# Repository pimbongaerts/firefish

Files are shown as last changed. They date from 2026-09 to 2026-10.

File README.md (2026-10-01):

# FireFish

### Real-time feedback &amp; synchronized sensor logging for underwater photogrammetry

An open-source microcontroller board that supports a wide range of sensors, and gives divers real-time
depth/altitude feedback, drives a dual-channel camera intervalometer, and logs time-stamped sensor data —
small enough to fit inside the smallest BlueRobotics 2″ underwater housing.








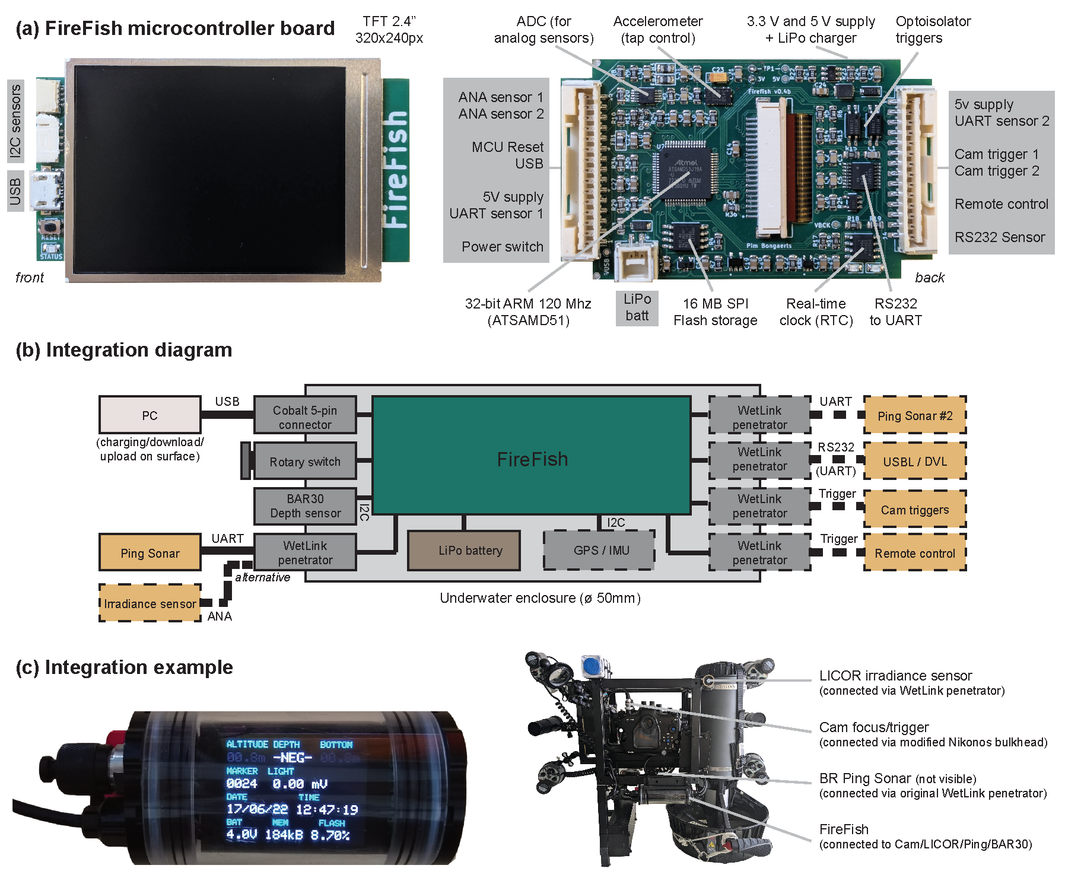
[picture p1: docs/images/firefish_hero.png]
The FireFish board (front and back), its system-integration diagram, and an example integration into a diver-propulsion-vehicle photogrammetry rig showing the live on-screen readout


---

## Overview

FireFish is a compact board that can provide scientific divers with (1) **real-time feedback** on depth, altitude,
and other positional data to guide image acquisition; (2) a programmable **dual-channel intervalometer** for one
or two cameras; and (3) **time-stamped logging** of sensor data that can be used for downstream photogrammetry model orientation. Its open design adapts well beyond photogrammetry — e.g. synchronized irradiance measurements or for underwater navigation – and provides an easy platform to make sensors designed for underwater vehicles accessible to divers.

<table>
<tr>
<td width="50%" valign="top">
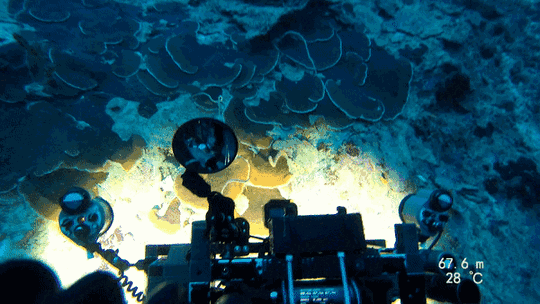
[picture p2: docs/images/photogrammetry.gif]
Diver conducting a coral-reef photogrammetry survey with FireFish

<br><sub><b>Photogrammetry.</b> The FireFish allows divers to maintain a fixed altitude from the live readout of a BlueRobotics Ping sonar, while simultaneously triggering a camera and logging depth/altitude for 3D-model orientation.</sub>
</td>
<td width="50%" valign="top">
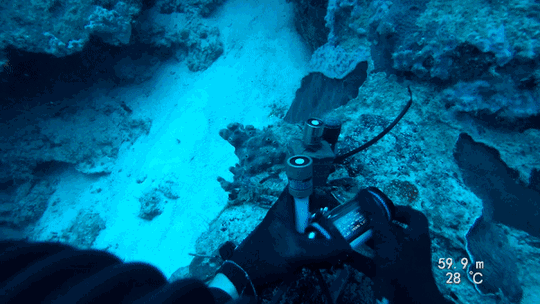
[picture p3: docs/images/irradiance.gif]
Diver logging underwater irradiance with FireFish

<br><sub><b>Irradiance measurements (alternative implementation).</b> The Reefscape Genomics Lab uses multiple FireFish units connected to LICOR irradiance sensors to conduct short-term irradiances measures across the reef, relative to time-synchronized measurements of the water column.</sub>
</td>
</tr>
</table>

## ✨ Features

- 🎯 **Live sensor readout** on a 2.4″ TFT — allowig divers to maintain a consistent altitude
- 📷 **Dual-channel intervalometer** — focus + shutter for one camera, or alternate-trigger two cameras
- ⏱️ **Synchronized logging** to onboard flash with a temperature-compensated RTC — easy model orientation
- 🔌 **Flexible I/O** — I²C (Qwiic / STEMMA QT), 2× UART, RS-232, and 2x analog inputs
- 🔋 **Onboard LiPo charging** — charge, download, and update firmware *through* the housing, no opening required
- 🤿 **Dive-ready** — fits standard 2″ (Ø50 mm) housings with 3D printed carrier; depth rating to 225 m
- 🛠️ **Fully open** — KiCad design, firmware, enclosure STLs, and an Arduino board-support package

## 🔧 Specifications

| | |
|---|---|
| **Microcontroller** | ATSAMD51J19A — 32-bit Arm Cortex-M4F, 120 MHz, hardware FPU |
| **Display** | 2.4″ TFT, 320 × 240 (ST7789) |
| **Storage** | 16 MB onboard SPI flash (MX25L12833F) |
| **Timekeeping** | DS3231MZ temperature-compensated RTC (battery-backed) |
| **Power** | MCP73831 single-cell LiPo charger; 3.3 V &amp; 5 V rails |
| **Sensing / I/O** | ADS1115 16-bit ADC; I²C, UART, RS-232 (MAX3232); tap gesture control |
| **Camera control** | Dual-channel optically-isolated intervalometer (TCMT1100) |
| **Board size** | 72 × 43 mm (two-layer PCB) |
| **Housing** | Standard 2″ (Ø50 mm) BlueRobotics enclosure; depth rating to 225 m |

## 📦 Repository contents

| Folder | Contents |
|---|---|
| [`hardware/`](hardware/) | KiCad 8 project — schematic, PCB layout, Gerbers, BOM, and pick-and-place files |
| [`firmware/`](firmware/) | Arduino board-support package (`firefish_m4_v4b`), an example sketch, and the bootloader |
| [`enclosure/`](enclosure/) | 3D-printable PETG carrier STLs (short / short-simple / long-simple) + clamp |
| [`docs/`](docs/) | Figures and documentation |

## Schematic

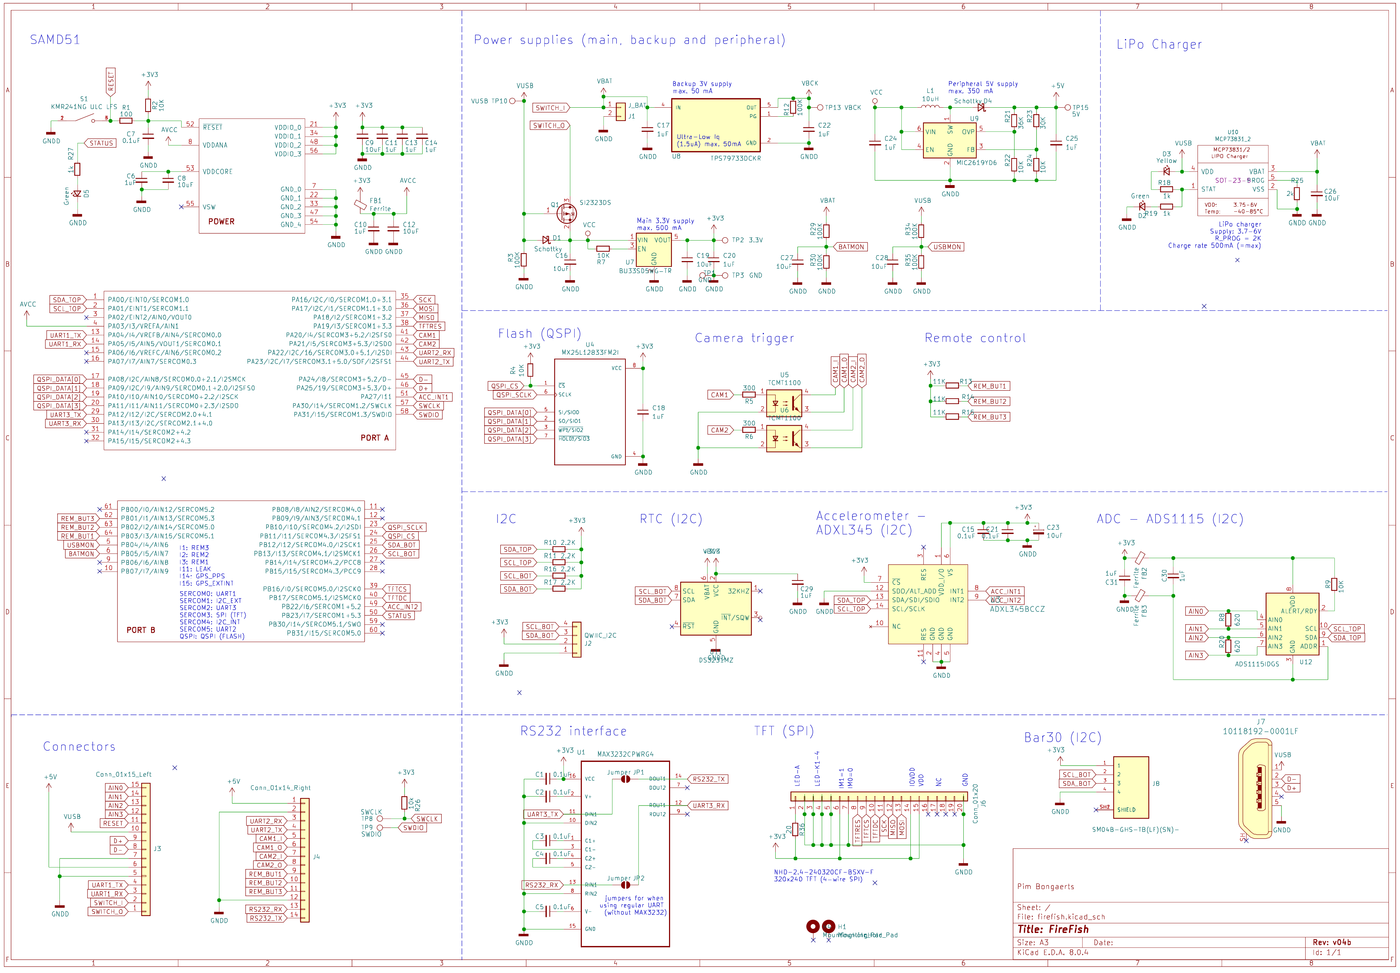
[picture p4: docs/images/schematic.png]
FireFish schematic


The full editable schematic is [`hardware/firefish.kicad_sch`](hardware/firefish.kicad_sch) (KiCad 8).

## 🛠️ Assembling a FireFish

The full step-by-step build and operation instructions are in the HardwareX article (see [Citation](#citation));
this repository holds the files those instructions refer to:

- [`hardware/`](hardware/) — fabricate and populate the board (Gerbers + BOM + placement files)
- [`firmware/`](firmware/) — flash the bootloader (J-Link) and upload the example sketch over USB
- [`enclosure/`](enclosure/) — slide the board into 3D printed carrier and place into a 2″ housing

## Citation

If you use FireFish, please cite the article:

> Bongaerts, P. (2026). *FireFish: an open-source microcontroller for real-time sensor feedback and data logging in underwater photogrammetry.* **HardwareX** (under review).

```bibtex
@article{Bongaerts2026FireFish,
  author  = {Bongaerts, Pim},
  title   = {FireFish: an open-source microcontroller for real-time sensor
             feedback and data logging in underwater photogrammetry},
  journal = {HardwareX},
  year    = {2026},
  note    = {Under review; DOI to be added}
}
```

> 📌 The archival version of record (design files + firmware) is deposited on **Zenodo**:
> [https://doi.org/10.5281/zenodo.23073946](https://doi.org/10.5281/zenodo.23073946). This GitHub repository is the development mirror.

## ⚖️ License

Open-source hardware, licensed by part (full details in [`LICENSE.md`](LICENSE.md)):

| Part | License |
|---|---|
| **Hardware** — KiCad, Gerbers, STLs, BOM | [CERN-OHL-S v2](LICENSE-HARDWARE.txt) |
| **Software / firmware** — original code | [MIT](LICENSE-SOFTWARE.txt) |
| **Documentation &amp; figures** | [CC BY 4.0](LICENSE-DOCS.txt) |

Third-party firmware keeps its upstream license (Adafruit SAMD core → LGPL-2.1; uf2-samdx1 → MIT; ChaN FatFs → BSD-style). Copyright © 2024–2026 Pim Bongaerts.

<sub>Figures © Pim Bongaerts, reproduced from the FireFish HardwareX article under CC BY 4.0.</sub>

## 🙏 Acknowledgments

Built by learning from the open-source hardware community — in particular **Adafruit** and **SparkFun** — with
generous input from **John Atkins** and **Joey Castillo**. Field testing and deployment were supported by the
**Hope for Reefs Initiative** at the **California Academy of Sciences** and **Inkfish**.

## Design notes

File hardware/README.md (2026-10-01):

# Hardware — FireFish PCB

Canonical **KiCad 8** design for the FireFish board (ATSAMD51J19A), plus the fabrication
outputs used for the PCBWay build. Licensed **CERN-OHL-S v2** (see repo `LICENSE.md`).

## Schematic

FireFish schematic

> Rendered overview of the schematic. The authoritative, editable source is
> `firefish.kicad_sch` (KiCad 8).

## Contents
```
firefish.kicad_pro            KiCad 8 project
firefish.kicad_sch            schematic (symbols embedded)
firefish.kicad_pcb            2-layer PCB layout (footprints embedded)
firefish-rescue.kicad_sym     rescued symbols (referenced by the schematic)
sym-lib-table / fp-lib-table  project library tables (cleaned — see note)
firefish_BOM_pcbway2024.csv   authoritative BOM (matches the assembled board)
gerbers/                      fabrication: F/B copper, mask, paste, silkscreen,
                              Edge_Cuts, + PTH/NPTH drill files (2024-08-23)
placement/PCBWay_positions.csv  pick-and-place / component positions (2024-08-23)
```

## Opening the project
The schematic and PCB are **self-contained**: KiCad 8 embeds all used symbols
(`lib_symbols`) and footprints, so the project opens, renders, and can be re-plotted
without any external libraries.

## Note on library tables
The original `sym-lib-table` / `fp-lib-table` referenced libraries by **absolute local
paths** (e.g. the Digi-Key KiCad library and custom footprint folders on the author's
machine) that would be broken for anyone else. Those entries were removed for this
deposit; only the project-local `firefish-rescue` symbol library is retained. This does
not affect viewing, plotting, or fabrication — only *editing a placed part from its
original source library* would require re-adding that library locally. Custom footprints
used include the Digi-Key KiCad library, an Open Book (`OSO-BOOK-A1-06`) footprint, and a
custom Molex 52271-2069 footprint.

## Fabrication summary
- 2-layer PCB. Gerbers + drills as fabricated by PCBWay (2024-08-23).
- BOM cross-checked against the layout: all 93 placed components accounted for; JP1/JP2
  are open solder-bridge jumpers (not populated). See manuscript §4 / repo BOM.

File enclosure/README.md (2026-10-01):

# Enclosure

3D-printable **carrier** that holds the FireFish board inside a standard BlueRobotics 2″
(⌀ 50 mm) underwater housing, plus a clamp. Modeled in **Blender 4.0.2**; print in PETG at
100% infill.

## Files

| File | Variant | Notes |
| --- | --- | --- |
| `firefish_carrier_short.stl` | short, detailed | Carrier with connector cut-outs and support to secure the battery against the board. For the ⌀ 50 × 100 mm BlueRobotics enclosure. |
| `firefish_carrier_short_simple.stl` | short, simplified | Simplified geometry, for the ⌀ 50 × 100 mm BlueRobotics enclosure. |
| `firefish_carrier_long_simple.stl` | long, simplified  | Longer simplified variant, for the ⌀ 50 × 150 mm BlueRobotics enclosure. |
| `firefish_enclosure_clamp.stl` | clamp | Adds a boltsnap attachment point to the BlueRobotics enclosure. |
| `firefish_enclosure_mount_short.stl` | short | Mount for the ⌀ 50 × 100 mm BlueRobotics enclosure to attach it to 1-inch aluminium square tubing. |
| `firefish_enclosure_mount_long.stl` | long | Mount for the ⌀ 50 × 150 mm BlueRobotics enclosure to attach it to 1-inch aluminium square tubing. |
| `firefish_enclosure_blacktip_mount.stl` | short | Mount for the ⌀ 50 × 100 mm BlueRobotics enclosure to attach directly to a Dive Xtras Blacktip. |

All are binary STL and mate with a standard BlueRobotics 2″ underwater housing.

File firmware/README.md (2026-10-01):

# Firmware & software

Everything needed to build for and operate the FireFish board (ATSAMD51J19A).

```
board-support/firefish_m4_v4b/   Arduino board-support package (board definition,
                                 pin variant, linker scripts, bootloader, package index)
examples/firefish_m4_2025v2/     Example sketch — dive data-logger + camera intervalometer
```

## Board support

FireFish's Arduino support is a **variant layered on the Adafruit SAMD core**, not a
standalone core — only the FireFish-specific files are included here. Board id
`firefish_m4_v4b`, display name **FireFish M4 v0.4b**.

1. In the Arduino IDE, install **Adafruit SAMD Boards core v1.7.10** (Boards Manager →
   "Adafruit SAMD Boards"). This variant was built against that version.
2. Copy the FireFish delta into the installed platform folder (on macOS, e.g.
   `~/Library/Arduino15/packages/adafruit/hardware/samd/1.7.10/`):
   - `boards.local.txt` → platform root (Arduino merges it with the core's `boards.txt`;
     **FireFish M4 v0.4b** then appears under *Tools ▸ Board*).
   - `variants/firefish_m4_v4b/` → the platform's `variants/` folder.
   - `bootloaders/firefish_m4/` → the platform's `bootloaders/` folder.

`package_firefish_index.json` is included for anyone who wants to publish a self-contained
Boards-Manager package instead (requires rebuilding a full-core zip and regenerating the
index checksum/size/url).

## Bootloader

UF2 bootloader based on Adafruit's **uf2-samdx1**, version `v3.13.0-9-g2fd0593` (the
bootloader-software version, independent of the board revision). In bootloader mode the
board enumerates as the **FIREBOOT** drive.

- `bootloaders/firefish_m4/*.bin` — flashable image (via SWD: J-Link + Microchip Studio, or OpenOCD).
- `*.uf2` / `*.ino` — self-updater: drag the `.uf2` onto the FIREBOOT drive to update the bootloader without a programmer.

**Building from source.** The only FireFish-specific files are the board definition in
`bootloaders/firefish_m4/source/` (`board_config.h` + `board.mk`); everything else comes
straight from upstream. Rebuild against the exact pinned commit (needs the ARM GCC toolchain):

```sh
git clone --recursive https://github.com/adafruit/uf2-samdx1
cd uf2-samdx1
git checkout 2fd0593            # = v3.13.0-9-g2fd0593
mkdir -p boards/firefish_m4
cp /path/to/source/board_config.h boards/firefish_m4/
cp /path/to/source/board.mk       boards/firefish_m4/
make BOARD=firefish_m4
```

## Example sketch

`examples/firefish_m4_2025v2/` is a typical use case: a real-time underwater data logger
and camera intervalometer. It reads the Bar30 depth sensor, Ping sonar altimeter, ADS1115
(LI-COR irradiance), RTC, and ADXL345 over I²C/SPI; shows live values on the ST7789 TFT;
triggers camera focus/shutter on an interval; and logs time-stamped records to a `data.csv`
on the onboard SPI flash (via ChaN **FatFs**). See the header comment in the `.ino` for
details, and the HardwareX article for operation.

Arduino library dependencies: Wire, SPI, Adafruit_GFX, Adafruit_ST7789, Adafruit_ADS1X15,
Adafruit_SPIFlash, Adafruit_I2CDevice, MS5837, RTClib, SparkFun_ADXL345, ping1d (Blue
Robotics), SdFat.

## Licensing

Original FireFish code is **MIT** (repo `LICENSE-SOFTWARE.txt`). Third-party files keep
their upstream licenses: Adafruit SAMD core / variant files → LGPL-2.1; uf2-samdx1
bootloader → MIT; ChaN FatFs (`ff.*`, `diskio.h`) → BSD-style. See `../LICENSE.md`.

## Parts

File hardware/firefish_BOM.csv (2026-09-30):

Item # | Designator | Qty | Manufacturer | Mfg Part # | Description / Value | Package | Type | Your Instructions / Notes | Previously used JLCPCB Part # | Footprint
1 | C1,C2,C3,C4,C5,C7,C15,C21 | 8 |  |  | 0.1uF ±10% | 0805 | SMD | Any manufacturer | C49678 | Capacitor_SMD:C_0805_2012Metric_Pad1.15x1.40mm_HandSolder
2 | C23 | 1 |  |  | 10uF ±10% | CASE-A-3216-18(mm) | SMD | Any manufacturer | C7171 | Capacitor_Tantalum_SMD:CP_EIA-3216-18_Kemet-A
3 | C6,C10,C11,C13,C14,C17,C18,C20,C22,C24,C25,C29,C30,C31 | 14 |  |  | 1uF ±10% | 0805 | SMD | Any manufacturer | C28323 | Capacitor_SMD:C_0805_2012Metric_Pad1.15x1.40mm_HandSolder
4 | C8,C9,C12,C16,C19,C26,C27,C28 | 8 |  |  | 10uF ±10% | 0805 | SMD | Any manufacturer | C15850 | Capacitor_SMD:C_0805_2012Metric_Pad1.15x1.40mm_HandSolder
5 | R1 | 1 |  |  | 100 ±1% | 0805 | SMD | Any manufacturer | C17408 | Resistor_SMD:R_0805_2012Metric_Pad1.15x1.40mm_HandSolder
6 | R10,R11,R16,R17 | 4 |  |  | 2.2K ±1% | 0805 | SMD | Any manufacturer | C17520 | Resistor_SMD:R_0805_2012Metric_Pad1.15x1.40mm_HandSolder
7 | R13,R14,R15 | 3 |  |  | 11K ±1% | 0805 | SMD | Any manufacturer | C17429 | Resistor_SMD:R_0805_2012Metric_Pad1.15x1.40mm_HandSolder
8 | R18,R19,R27 | 3 |  |  | 1k ±1% | 0805 | SMD | Any manufacturer | C17513 | Resistor_SMD:R_0805_2012Metric_Pad1.15x1.40mm_HandSolder
9 | R2,R4,R7,R9,R22,R24 | 6 |  |  | 10K ±1% | 0805 | SMD | Any manufacturer | C17414 | Resistor_SMD:R_0805_2012Metric_Pad1.15x1.40mm_HandSolder
10 | R21 | 1 |  |  | 36K ±1% | 0805 | SMD | Any manufacturer | C4360 | Resistor_SMD:R_0805_2012Metric_Pad1.15x1.40mm_HandSolder
11 | R23 | 1 |  |  | 30K ±1% | 0805 | SMD | Any manufacturer | C17621 | Resistor_SMD:R_0805_2012Metric_Pad1.15x1.40mm_HandSolder
12 | R25 | 1 |  |  | 2k ±1% | 0805 | SMD | Any manufacturer | C17604 | Resistor_SMD:R_0805_2012Metric_Pad1.15x1.40mm_HandSolder
13 | R26 | 1 |  |  | 10k ±1% | 0805 | SMD | Any manufacturer | C17414 | Resistor_SMD:R_0805_2012Metric_Pad1.15x1.40mm_HandSolder
14 | R3,R12,R29,R30,R34,R35 | 6 |  |  | 100K ±1% | 0805 | SMD | Any manufacturer | C17422 | Resistor_SMD:R_0805_2012Metric_Pad1.15x1.40mm_HandSolder
15 | R36 | 1 |  |  | 20 ±1% | 0805 | SMD | Any manufacturer | C17544 | Resistor_SMD:R_0805_2012Metric_Pad1.15x1.40mm_HandSolder
16 | R5,R6 | 2 |  |  | 300 ±1% | 0805 | SMD | Any manufacturer | C17617 | Resistor_SMD:R_0805_2012Metric_Pad1.15x1.40mm_HandSolder
17 | R8,R20 | 2 |  |  | 620 ±1% | 0805 | SMD | Any manufacturer |  | Resistor_SMD:R_0805_2012Metric_Pad1.15x1.40mm_HandSolder
18 | D1,D4 | 2 | Jiangsu Changjing Electronics Technology Co., Ltd. | B5819W SL | Schottky 40V 600mV@1A | SOD-123F | SMD | Any equivalent fine too | C8598 | Diode_SMD:D_SOD-123F
19 | D2,D5 | 2 | Hubei KENTO Elec | KT-0805G | Emerald | 0805 | SMD | Any equivalent fine too | C2297 | LED_SMD:LED_0805_2012Metric_Pad1.15x1.40mm_HandSolder
20 | D3 | 1 | Hubei KENTO Elec | KT-0805Y | Yellow | 0805 | SMD | Any equivalent fine too | C2296 | LED_SMD:LED_0805_2012Metric_Pad1.15x1.40mm_HandSolder
21 | FB1,FB2,FB3 | 3 | TDK | MMZ2012Y102BT000 | Ferrite 300m½ ±25% 1k½@100MHz 0805 Ferrite Beads | 0805 | SMD | Any equivalent fine too | C76810 | 0805
22 | J1 | 1 | Molex | 502443-0270 | J_BAT | Connector_Molex:Molex_CLIK-Mate_502443-0270_1x02-1MP_P2.00mm_Vertical | SMD |  |  | Connector_Molex:Molex_CLIK-Mate_502443-0270_1x02-1MP_P2.00mm_Vertical
23 | J2 | 1 | JST | SM04B-SRSS-TB | QWIIC_I2C | Connector_JST:JST_SH_SM04B-SRSS-TB_1x04-1MP_P1.00mm_Horizontal | SMD | Any equivalent fine too |  | Connector_JST:JST_SH_SM04B-SRSS-TB_1x04-1MP_P1.00mm_Horizontal
24 | J3 | 1 | Molex | 502443-1570 | Conn_01x15_Left | Connector_Molex:Molex_CLIK-Mate_502443-1570_1x15-1MP_P2.00mm_Vertical | SMD |  |  | Connector_Molex:Molex_CLIK-Mate_502443-1570_1x15-1MP_P2.00mm_Vertical
25 | J4 | 1 | Molex | 502443-1470 | Conn_01x14_Right | Connector_Molex:Molex_CLIK-Mate_502443-1470_1x14-1MP_P2.00mm_Vertical | SMD |  |  | Connector_Molex:Molex_CLIK-Mate_502443-1470_1x14-1MP_P2.00mm_Vertical
26 | J6 | 1 | Molex | 52271-2069 | Conn_01x20 | 52271:Molex-52271-2069-Manufacturer_Recommended | SMD |  |  | 52271:Molex-52271-2069-Manufacturer_Recommended
27 | J7 | 1 | Amphenol ICC | 10118192-0001LF | 10118192-0001LF | digikey-footprints:USB_Micro_B_Female_10118192 | SMD | Any equivalent fine too | C132564 | digikey-footprints:USB_Micro_B_Female_10118192
28 | J8 | 1 | JST | SM04B-GHS-TB | SM04B-GHS-TB(LF)(SN)- | SM04B-GHS-TB_LF__SN_-:JST_SM04B-GHS-TB(LF)(SN)- | SMD | Any equivalent fine too |  | SM04B-GHS-TB_LF__SN_-:JST_SM04B-GHS-TB(LF)(SN)-
29 | L1 | 1 | Murata Electronics | LQH32PN100MNCL | 10uH | 1210 | SMD | Any equivalent fine too | C86073 | LQH32PN100MN0L:IND_LQH32PN100MN0L
30 | Q1 | 1 | Vishay Siliconix | SI2323DS-T1 | SI2323DS | SOT-23 | SMD | Any equivalent fine too | C75561 | Package_TO_SOT_SMD:SOT-23
31 | S1 | 1 | C&K | KMR211NGLFS | KMR211NGLFS | KMR211NGLFS:SW_KMR211NGLFS | SMD | Any equivalent fine too |  | KMR211NGLFS:SW_KMR211NGLFS
32 | U1 | 1 | Texas Instruments | MAX3232CPWRG4 | MAX3232CPWRG4 | 16-TSSOP | SMD | Any equivalent fine too |  | MAX3232CPWRG4:SOP65P640X120-16N
33 | U10 | 1 | Microchip Tech | MCP73831T-2ACI/OT | MCP73831_2 | SOT-23-5 | SMD | Any equivalent fine too | C424093 | SOT-23-5
34 | U11 | 1 | Analog Devices Inc./Maxim Integrated | DS3231MZ+TRL | DS3231MZ | Package_SO:SOIC-8_3.9x4.9mm_P1.27mm | SMD | Any equivalent fine too | C107410 | Package_SO:SOIC-8_3.9x4.9mm_P1.27mm
35 | U12 | 1 | Texas Instruments | ADS1115IDGSR | ADS1115IDGS | Package_SO:MSOP-10_3x3mm_P0.5mm | SMD | Any equivalent fine too | C37593 | Package_SO:MSOP-10_3x3mm_P0.5mm
36 | U2 | 1 | Microchip Technology | ATSAMD51J19A-AU | ATSAMD51J64-TQFP(10X10) | 64-TQFP | SMD | Any equivalent fine too |  | OSO-BOOK-A1-06:TQFP64-10X10
37 | U3 | 1 | Analog Devices | ADXL345BCCZ-RL7 | ADXL345BCCZ | LGA-14(3x5) | SMD | Any equivalent fine too | C9667 | digikey-footprints:LGA-14_3x5mm_RevA
38 | U4 | 1 | MXIC(Macronix) | MX25L12833FM2I-10G | MX25L12833FM2I | SOP-8-200mil | SMD | Any equivalent fine too | C701355 | MX25L3233FM2I-08Q:SOIC127P790X216-8N
39 | U5,U6 | 2 | Vishay Intertech | TCMT1100 | TCMT1100 | SOP-4-1.27mm | SMD | Any equivalent fine too | C118298 | Package_SO:SOP-4_4.4x2.6mm_P1.27mm
40 | U7 | 1 | ROHM Semicon | BU33SD5WG-TR | BU33SD5WG-TR | SC-74A, SOT-753 | SMD | Any equivalent fine too |  | SOT95P280X125-5N:SOT95P280X125-5N
41 | U8 | 1 | Texas Instruments | TPS79733DCKR | TPS79733DCKR | 5-TSSOP, SC-70-5, SOT-353 | SMD | Any equivalent fine too |  | SOT65P210X110-5N:SOT65P210X110-5N
42 | U9 | 1 | Microchip Technology | MIC2619YD6-TR | MIC2619YD6 | TSOT-23-6 | SMD | Any equivalent fine too |  | Package_TO_SOT_SMD:TSOT-23-6

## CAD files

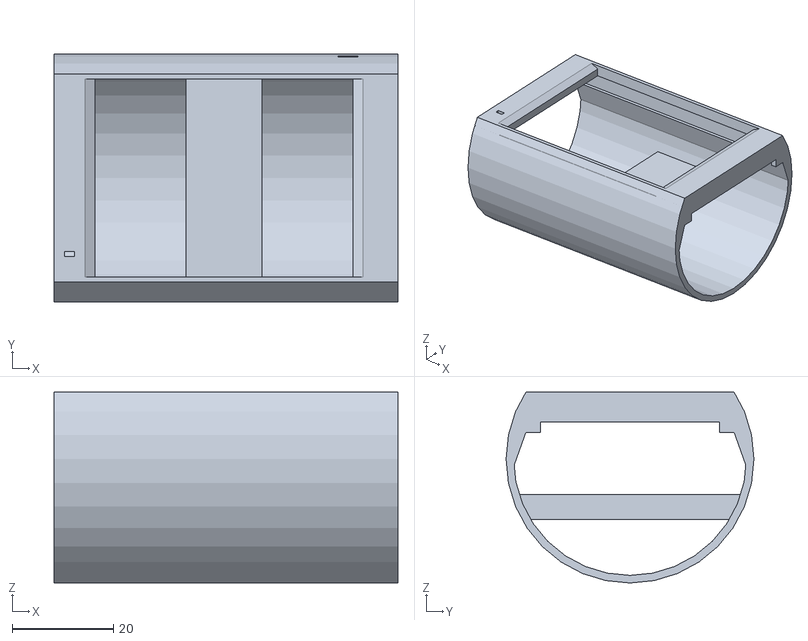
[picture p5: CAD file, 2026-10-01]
enclosure/firefish_carrier_short.stl
68.0 x 49.0 x 37.8

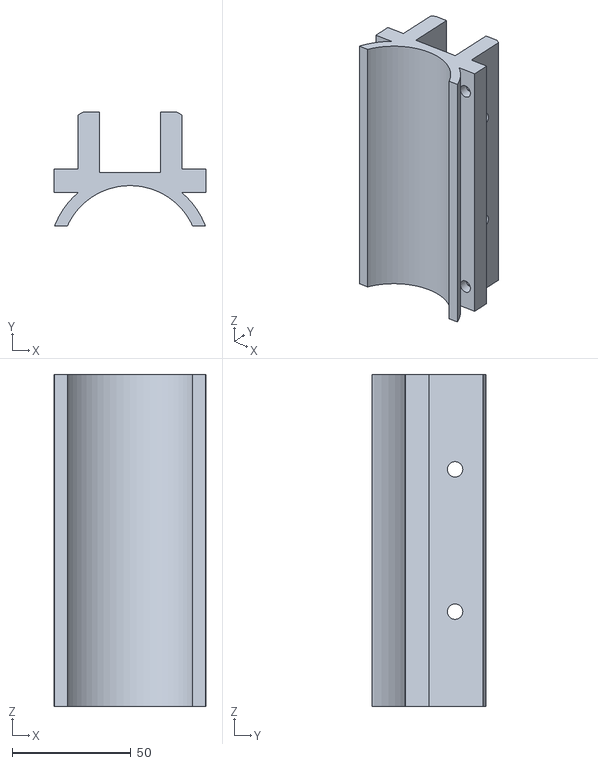
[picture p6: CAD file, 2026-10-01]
enclosure/firefish_enclosure_mount_long.stl
64.0 x 48.0 x 140.0

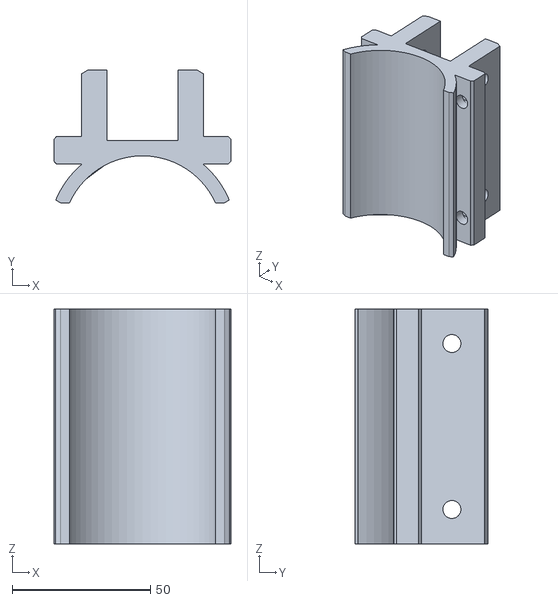
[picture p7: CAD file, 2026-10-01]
enclosure/firefish_enclosure_mount_short.stl
64.0 x 48.0 x 85.0

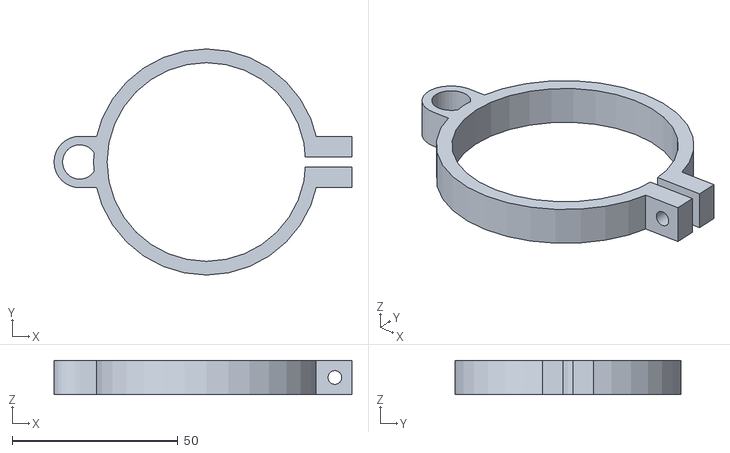
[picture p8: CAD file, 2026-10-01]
enclosure/firefish_enclosure_clamp.stl
90.0 x 68.2 x 10.3

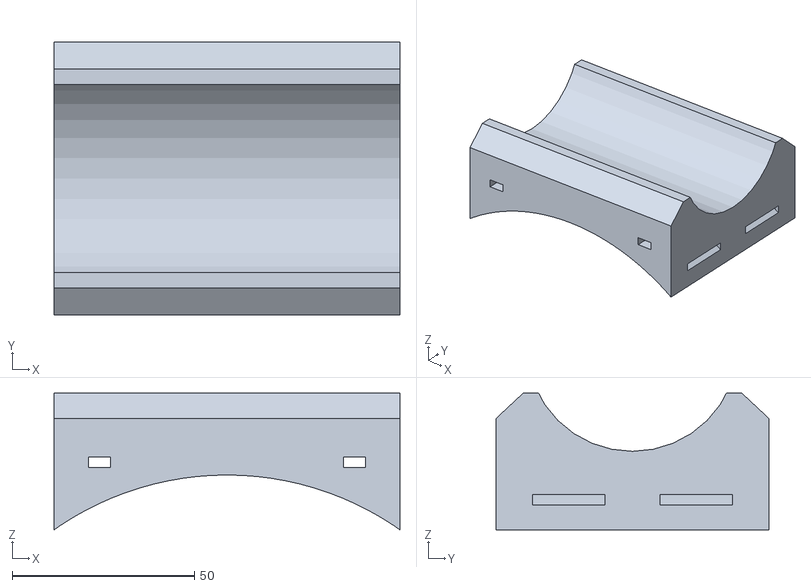
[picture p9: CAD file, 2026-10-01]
enclosure/firefish_enclosure_blacktip_mount.stl
95.0 x 75.0 x 37.6

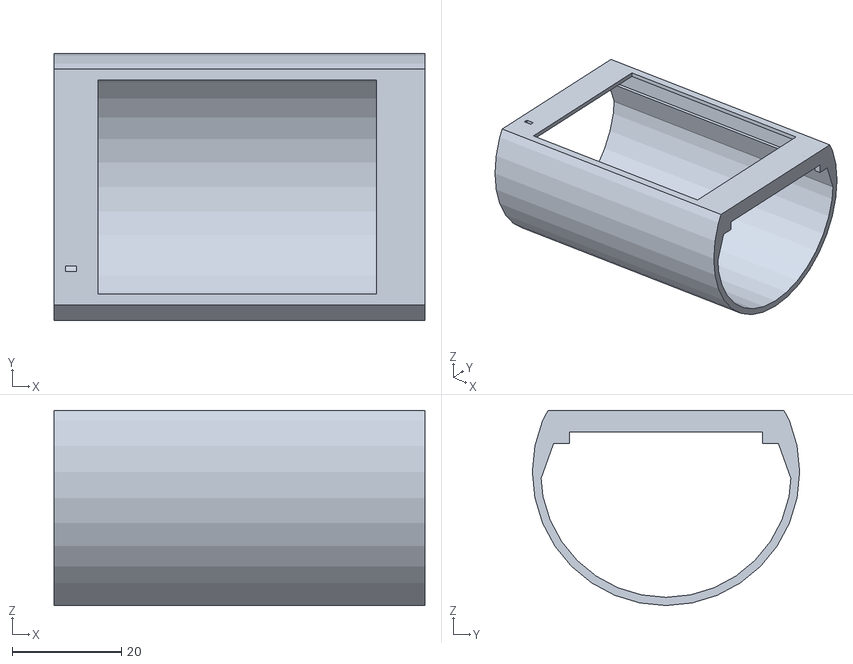
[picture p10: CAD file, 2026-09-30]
enclosure/firefish_carrier_short_simple.stl
68.0 x 49.0 x 35.8

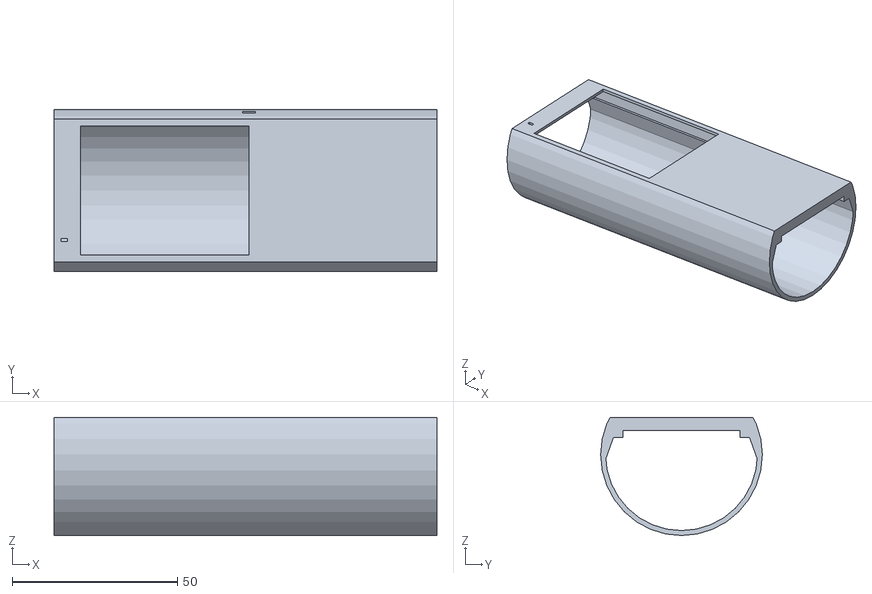
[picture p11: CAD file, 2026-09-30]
enclosure/firefish_carrier_long_simple.stl
116.0 x 49.0 x 35.8

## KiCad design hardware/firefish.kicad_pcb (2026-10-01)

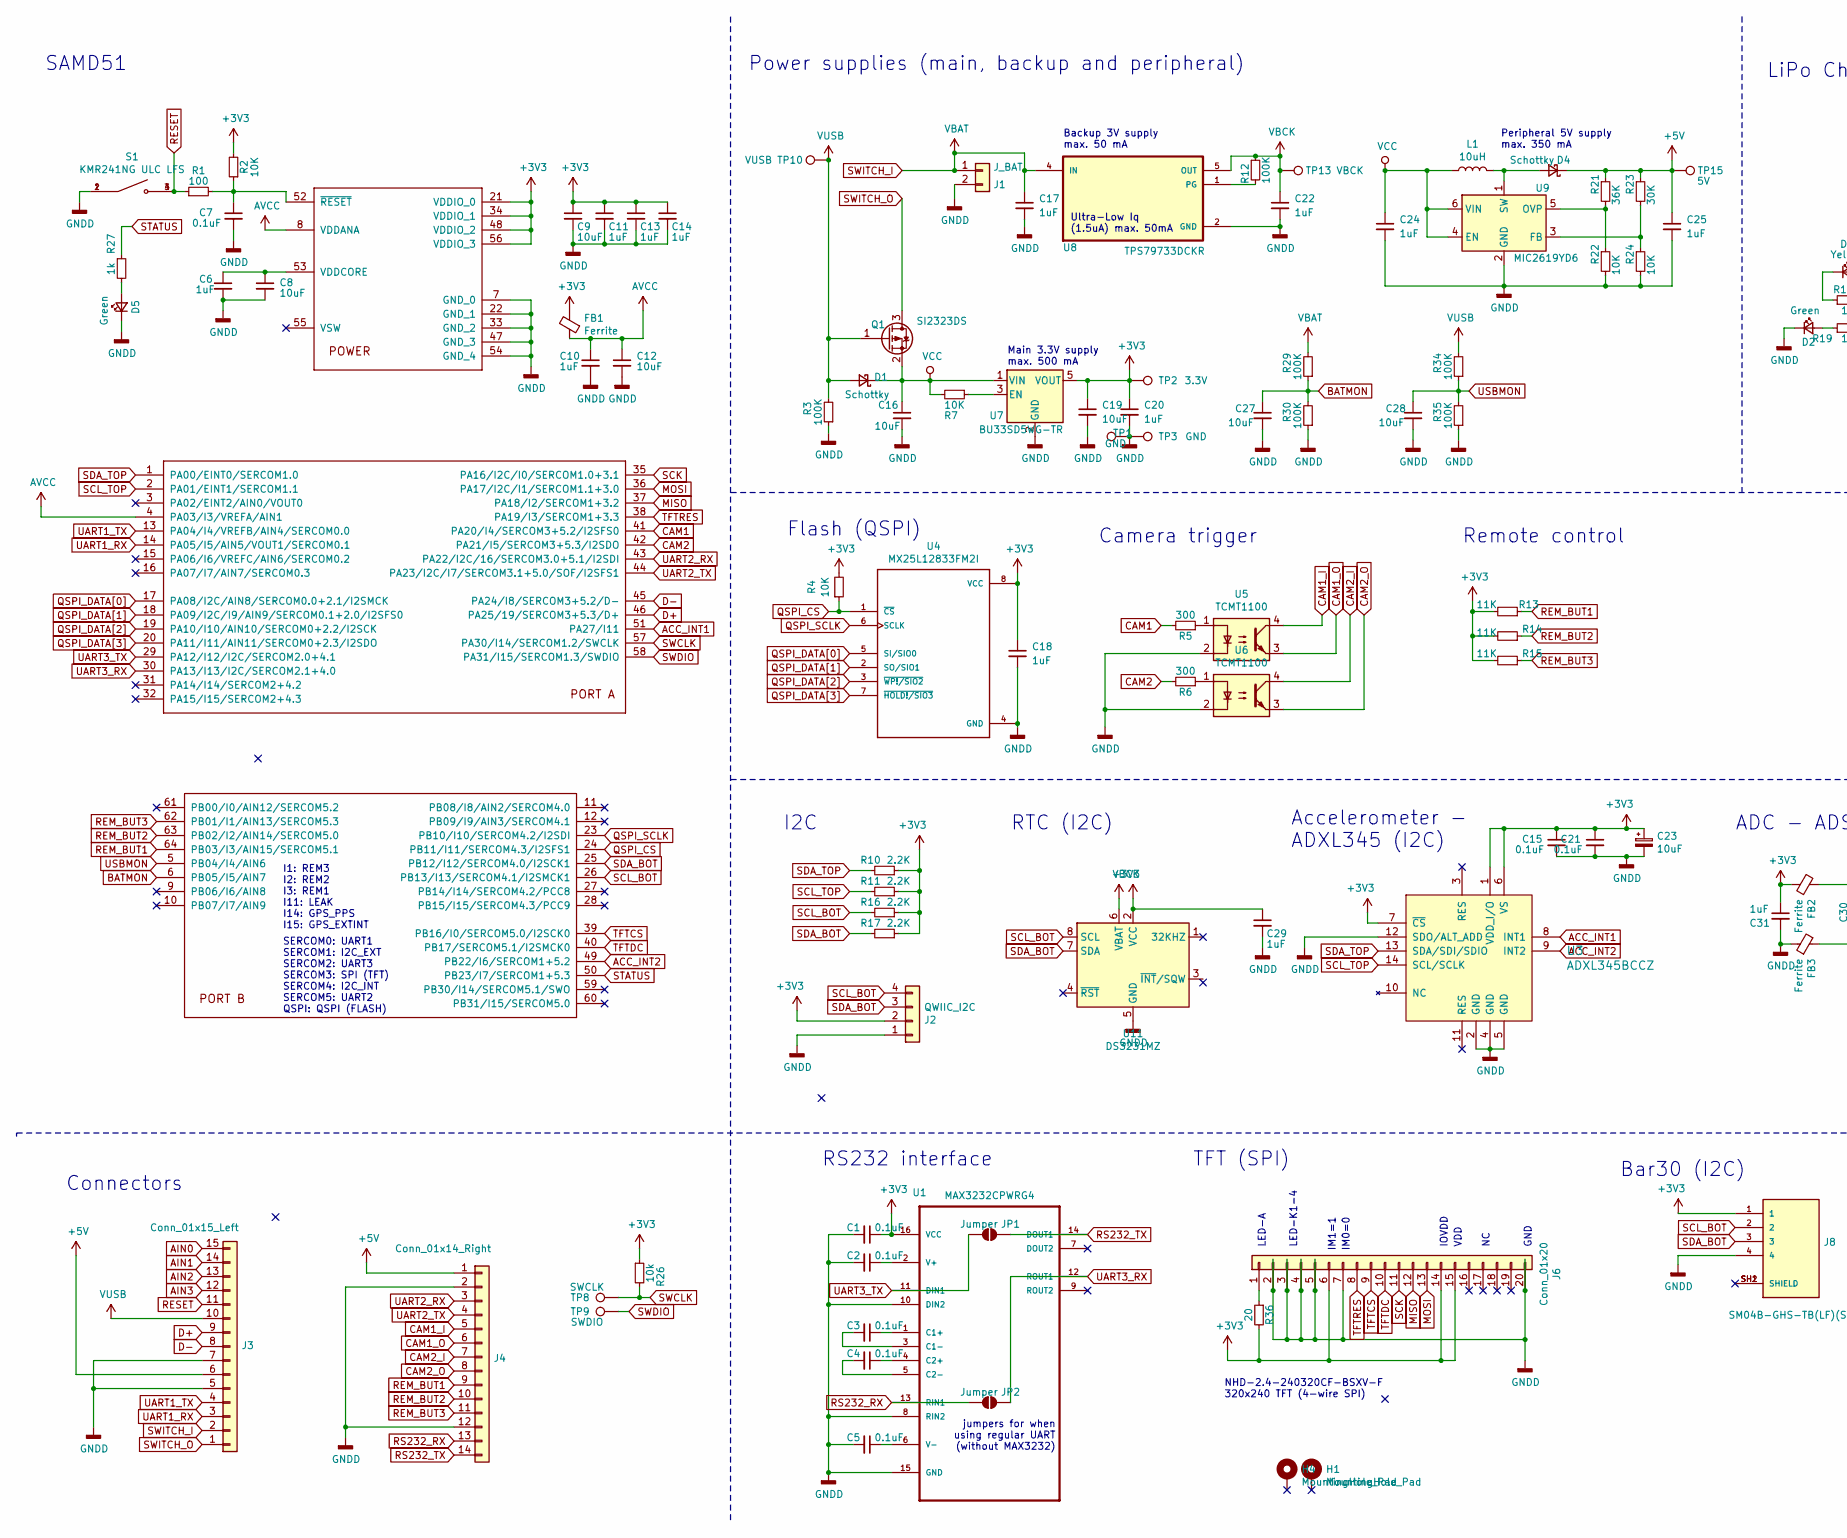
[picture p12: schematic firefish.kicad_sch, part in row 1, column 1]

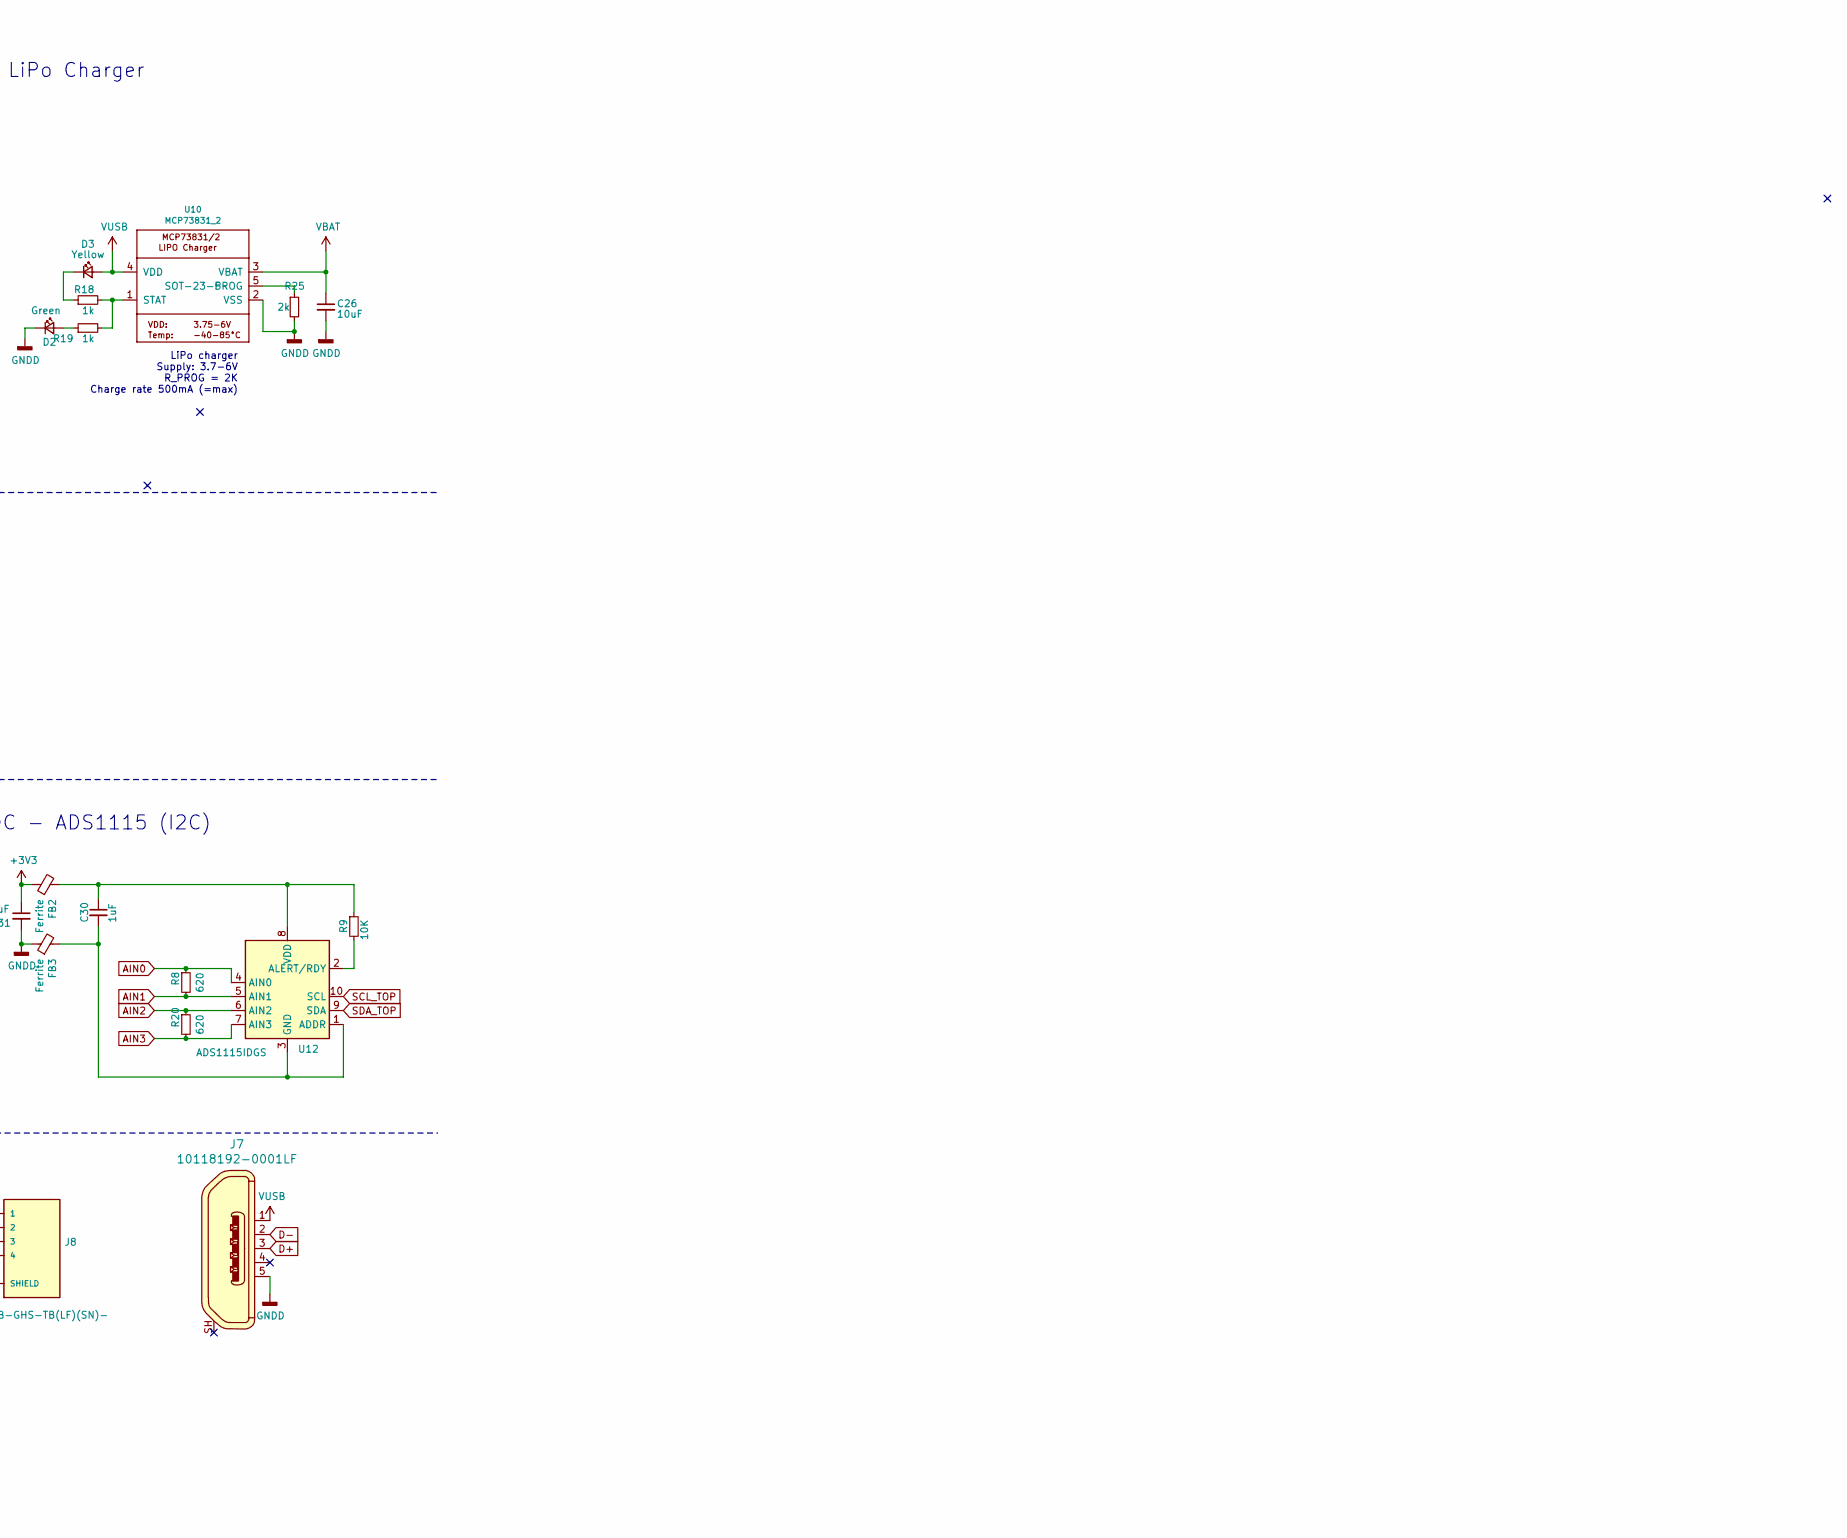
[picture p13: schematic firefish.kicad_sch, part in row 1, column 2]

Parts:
C1, C2, C3, C4, C7, C15, C21: 0.1uF; C_0805_2012Metric_Pad1.15x1.40mm_HandSolder; LCSC C49678
C5: 0.1uF; C_0805_2012Metric_Pad1.15x1.40mm_HandSolder
C6, C10, C11, C13, C14, C17, C18, C20, C22, C24, C25, C29, C30, C31: 1uF; C_0805_2012Metric_Pad1.15x1.40mm_HandSolder; LCSC C28323
C8, C9, C12, C16, C19, C26, C27, C28: 10uF; C_0805_2012Metric_Pad1.15x1.40mm_HandSolder; LCSC C15850
C23: 10uF; CP_EIA-3216-18_Kemet-A; LCSC C7171
D1, D4: Schottky; D_SOD-123F; LCSC C8598
D2: Green; LED_0805_2012Metric_Pad1.15x1.40mm_HandSolder; LCSC C2297
D3: Yellow; LED_0805_2012Metric_Pad1.15x1.40mm_HandSolder; LCSC C2296
D5: Green; LED_0805_2012Metric_Pad1.15x1.40mm_HandSolder
FB1, FB2, FB3: Ferrite; 0805; LCSC C76810
H1, H4: MountingHole_Pad; Mountinghole_1.0-1.5mm
J1: J_BAT; Molex_CLIK-Mate_502443-0270_1x02-1MP_P2.00mm_Vertical
J2: QWIIC_I2C; JST_SH_SM04B-SRSS-TB_1x04-1MP_P1.00mm_Horizontal; digikey 455-1804-1-ND
J3: Conn_01x15_Left; Molex_CLIK-Mate_502443-1570_1x15-1MP_P2.00mm_Vertical; digikey WM2281CT-ND
J4: Conn_01x14_Right; Molex_CLIK-Mate_502443-1470_1x14-1MP_P2.00mm_Vertical
J6: Conn_01x20; Molex-52271-2069-Manufacturer_Recommended; digikey ‎WM7946CT-ND‎
J7: 10118192-0001LF; USB_Micro_B_Female_10118192; MPN 10118192-0001LF; Digi-Key_PN 609-4613-1-ND
J8: SM04B-GHS-TB(LF)(SN)-; JST_SM04B-GHS-TB(LF)(SN)-; PARTREV NA
JP1, JP2: Jumper; SolderJumper-2_P1.3mm_Open_RoundedPad1.0x1.5mm
L1: 10uH; IND_LQH32PN100MN0L; LCSC C86073
Q1: SI2323DS; SOT-23; LCSC C75561
R1: 100; R_0805_2012Metric_Pad1.15x1.40mm_HandSolder; LCSC C17408
R2, R4, R7, R9, R22, R24: 10K; R_0805_2012Metric_Pad1.15x1.40mm_HandSolder; LCSC C17414
R3, R12, R29, R30, R34, R35: 100K; R_0805_2012Metric_Pad1.15x1.40mm_HandSolder; LCSC C17422
R5, R6: 300; R_0805_2012Metric_Pad1.15x1.40mm_HandSolder; LCSC C17617
R8, R20: 620; R_0805_2012Metric_Pad1.15x1.40mm_HandSolder
R10, R11, R16, R17: 2.2K; R_0805_2012Metric_Pad1.15x1.40mm_HandSolder; LCSC C17520
R13, R14, R15: 11K; R_0805_2012Metric_Pad1.15x1.40mm_HandSolder; LCSC C17429
R18, R19, R27: 1k; R_0805_2012Metric_Pad1.15x1.40mm_HandSolder; LCSC C17513
R21: 36K; R_0805_2012Metric_Pad1.15x1.40mm_HandSolder; LCSC C4360
R23: 30K; R_0805_2012Metric_Pad1.15x1.40mm_HandSolder; LCSC C17621
R25: 2k; R_0805_2012Metric_Pad1.15x1.40mm_HandSolder; LCSC C17604
R26: 10k; R_0805_2012Metric_Pad1.15x1.40mm_HandSolder; LCSC C17414
R36: 20; R_0805_2012Metric_Pad1.15x1.40mm_HandSolder; LCSC C17544
S1: KMR241NG ULC LFS‎; SW_KMR211NGLFS; PARTREV 8 jun 16; digikey CKN10285CT-ND‎
TP1, TP3: GND; TestPoint_Pad_D1.0mm
TP2: 3.3V; TestPoint_Pad_D1.0mm
TP8: SWCLK; TestPoint_Pad_D1.0mm
TP9: SWDIO; TestPoint_Pad_D1.0mm
TP10: VUSB; TestPoint_Pad_D1.0mm
TP13: VBCK; TestPoint_Pad_D1.0mm
TP15: 5V; TestPoint_Pad_D1.0mm
U1: MAX3232CPWRG4; SOP65P640X120-16N; digikey 296-26153-5-ND
U2: ATSAMD51J64-TQFP(10X10); TQFP64-10X10
U3: ADXL345BCCZ; LGA-14_3x5mm_RevA; MPN ADXL345BCCZ; Digi-Key_PN ADXL345BCCZ-ND
U4: MX25L12833FM2I; SOIC127P790X216-8N; LCSC C701355
U5, U6: TCMT1100; SOP-4_4.4x2.6mm_P1.27mm; LCSC C118298
U7: BU33SD5WG-TR; SOT95P280X125-5N
U8: TPS79733DCKR; SOT65P210X110-5N; digikey 296-11990-1-ND‎
U9: MIC2619YD6; TSOT-23-6; digikey 576-3655-1-ND
U10: MCP73831_2; SOT-23-5; LCSC C424093
U11: DS3231MZ; SOIC-8_3.9x4.9mm_P1.27mm; digikey not available
U12: ADS1115IDGS; MSOP-10_3x3mm_P0.5mm; LCSC C37593

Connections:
+3V3: C1.1, C9.1, C11.1, C13.1, C14.1, C15.1, C18.1, C19.1, C20.1, C21.1, C23.1, C29.1, C31.1, FB1.2, FB2.1, J2.2, J6.6, J6.14, J6.15, J8.1, R2.2, R4.2, R10.1, R11.1, R13.2, R14.2, R15.2, R16.1, R17.1, R26.1, R36.2, TP2.1, U1.16 (VCC), U2.21 (VDDIO_0), U2.34 (VDDIO_1), U2.48 (VDDIO_2), U2.56 (VDDIO_3), U3.1 (VDD_I/O), U3.6 (VS), U3.7 (~CS), U4.8 (VCC), U7.5 (VOUT), U11.2 (VCC)
+5V: C25.1, D4.1 (K), J3.6, J4.1, R21.1, R23.1, TP15.1
ACC_INT1: U2.51 (PA27/I11), U3.8 (INT1)
ACC_INT2: U2.49 (PB22/I6/SERCOM1+5.2), U3.9 (INT2)
AIN0: J3.15, R8.1, U12.4 (AIN0)
AIN1: J3.14, R8.2, U12.5 (AIN1)
AIN2: J3.13, R20.1, U12.6 (AIN2)
AIN3: J3.12, R20.2, U12.7 (AIN3)
AVCC: C10.1, C12.1, FB1.1, U2.4 (PA03/I3/VREFA/AIN1), U2.8 (VDDANA)
BATMON: C27.1, R29.1, R30.2, U2.6 (PB05/I5/AIN7)
CAM1: R5.2, U2.41 (PA20/I4/SERCOM3+5.2/I2SFS0)
CAM1_I: J4.5, U5.4
CAM1_O: J4.6, U5.3
CAM2: R6.2, U2.42 (PA21/I5/SERCOM3+5.3/I2SDO)
CAM2_I: J4.7, U6.4
CAM2_O: J4.8, U6.3
D+: J3.9, J7.3, U2.46 (PA25/19/SERCOM3+5.3/D+)
D-: J3.8, J7.2, U2.45 (PA24/I8/SERCOM3+5.2/D-)
GNDD: C1.2, C2.2, C5.2, C6.2, C7.2, C8.2, C9.2, C10.2, C11.2, C12.2, C13.2, C14.2, C15.2, C16.2, C17.2, C18.2, C19.2, C20.2, C21.2, C22.2, C23.2, C24.2, C25.2, C26.2, C27.2, C28.2, C29.2, C31.2, D2.1 (K), D5.1 (K), FB3.1, J1.2, J2.1, J3.5, J3.7, J4.2, J4.12, J6.2, J6.3, J6.4, J6.5, J6.7, J6.20, J7.5, J8.4, R3.1, R22.2, R24.2, R25.2, R30.1, R35.1, S1.1, S1.2, TP1.1, TP3.1, U1.8 (RIN2), U1.10 (DIN2), U1.15 (GND), U2.7 (GND_0), U2.22 (GND_1), U2.33 (GND_2), U2.47 (GND_3), U2.54 (GND_4), U3.2 (GND), U3.4 (GND), U3.5 (GND), U3.12 (SDO/ALT_ADD), U4.4 (GND), U5.2, U6.2, U7.2 (GND), U8.2 (GND), U9.2 (GND), U10.2 (VSS), U11.5 (GND)
MISO: J6.12, U2.37 (PA18/I2/SERCOM1+3.2)
MOSI: J6.13, U2.36 (PA17/I2C/I1/SERCOM1.1+3.0)
unnamed: D2.2 (A), R19.1
unnamed: D3.1 (K), R18.1
unnamed: D4.2 (A), L1.2, U9.1 (SW)
unnamed: D5.2 (A), R27.2
unnamed: J6.1, R36.1
unnamed: R5.1, U5.1
unnamed: R6.1, U6.1
unnamed: C3.1, U1.1 (C1+)
unnamed: C3.2, U1.3 (C1-)
unnamed: C4.1, U1.4 (C2+)
unnamed: C4.2, U1.5 (C2-)
unnamed: C2.1, U1.2 (V+)
unnamed: C5.1, U1.6 (V-)
unnamed: C6.1, C8.1, U2.53 (VDDCORE)
unnamed: C7.1, R1.2, R2.1, U2.52 (~RESET)
unnamed: R7.1, U7.3 (EN)
unnamed: R12.2, U8.1 (PG)
unnamed: R23.2, R24.1, U9.3 (FB)
unnamed: R21.2, R22.1, U9.5 (OVP)
unnamed: R25.1, U10.5 (PROG)
unnamed: R18.2, R19.2, U10.1 (STAT)
unnamed: C30.2, FB3.2, U12.1 (ADDR), U12.3 (GND)
unnamed: R9.2, U12.2 (ALERT/RDY)
unnamed: C30.1, FB2.2, R9.1, U12.8 (VDD)
QSPI_CS: R4.1, U2.24 (PB11/I11/SERCOM4.3/I2SFS1), U4.1 (~CS)
QSPI_DATA[0]: U2.17 (PA08/I2C/AIN8/SERCOM0.0+2.1/I2SMCK), U4.5 (SI/SIO0)
QSPI_DATA[1]: U2.18 (PA09/I2C/I9/AIN9/SERCOM0.1+2.0/I2SFS0), U4.2 (SO/SIO1)
QSPI_DATA[2]: U2.19 (PA10/I10/AIN10/SERCOM0+2.2/I2SCK), U4.3 (~WP!/SIO2)
QSPI_DATA[3]: U2.20 (PA11/I11/AIN11/SERCOM0+2.3/I2SDO), U4.7 (~HOLD!/SIO3)
QSPI_SCLK: U2.23 (PB10/I10/SERCOM4.2/I2SDI), U4.6 (SCLK)
REM_BUT1: J4.9, R13.1, U2.64 (PB03/I3/AIN15/SERCOM5.1)
REM_BUT2: J4.10, R14.1, U2.63 (PB02/I2/AIN14/SERCOM5.0)
REM_BUT3: J4.11, R15.1, U2.62 (PB01/I1/AIN13/SERCOM5.3)
RESET: J3.11, R1.1, S1.3, S1.4
RS232_RX: J4.13, JP2.1 (A), U1.13 (RIN1)
RS232_TX: J4.14, JP1.2 (B), U1.14 (DOUT1)
SCK: J6.11, U2.35 (PA16/I2C/I0/SERCOM1.0+3.1)
SCL_BOT: J2.4, J8.2, R16.2, U2.26 (PB13/I13/SERCOM4.1/I2SMCK1), U11.8 (SCL)
SCL_TOP: R11.2, U2.2 (PA01/EINT1/SERCOM1.1), U3.14 (SCL/SCLK), U12.10 (SCL)
SDA_BOT: J2.3, J8.3, R17.2, U2.25 (PB12/I12/SERCOM4.0/I2SCK1), U11.7 (SDA)
SDA_TOP: R10.2, U2.1 (PA00/EINT0/SERCOM1.0), U3.13 (SDA/SDI/SDIO), U12.9 (SDA)
STATUS: R27.1, U2.50 (PB23/I7/SERCOM1+5.3)
SWCLK: R26.2, TP8.1, U2.57 (PA30/I14/SERCOM1.2/SWCLK)
SWDIO: TP9.1, U2.58 (PA31/I15/SERCOM1.3/SWDIO)
SWITCH_I: C17.1, C26.1, J1.1, J3.2, R29.2, U8.4 (IN), U10.3 (VBAT)
SWITCH_O: J3.1, Q1.3 (D)
TFTCS: J6.9, U2.39 (PB16/I0/SERCOM5.0/I2SCK0)
TFTDC: J6.10, U2.40 (PB17/SERCOM5.1/I2SMCK0)
TFTRES: J6.8, U2.38 (PA19/I3/SERCOM1+3.3)
UART1_RX: J3.3, U2.14 (PA05/I5/AIN5/VOUT1/SERCOM0.1)
UART1_TX: J3.4, U2.13 (PA04/I4/VREFB/AIN4/SERCOM0.0)
UART2_RX: J4.3, U2.43 (PA22/I2C/16/SERCOM3.0+5.1/I2SDI)
UART2_TX: J4.4, U2.44 (PA23/I2C/I7/SERCOM3.1+5.0/SOF/I2SFS1)
UART3_RX: JP2.2 (B), U1.12 (ROUT1), U2.30 (PA13/I13/I2C/SERCOM2.1+4.0)
UART3_TX: JP1.1 (A), U1.11 (DIN1), U2.29 (PA12/I12/I2C/SERCOM2.0+4.1)
USBMON: C28.1, R34.1, R35.2, U2.5 (PB04/I4/AIN6)
VBCK: C22.1, R12.1, TP13.1, U8.5 (OUT), U11.6 (VBAT)
VCC: C16.1, C24.1, D1.1 (K), L1.1, Q1.2 (S), R7.2, U7.1 (VIN), U9.4 (EN), U9.6 (VIN)
VUSB: D1.2 (A), D3.2 (A), J3.10, J7.1, Q1.1 (G), R3.2, R34.2, TP10.1, U10.4 (VDD)

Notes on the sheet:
Bar30 (I2C)
RTC (I2C)
SAMD51
IOVDD
TFT (SPI)
Ultra-Low Iq (1.5uA) max. 50mA
Flash (QSPI)
Camera trigger
Main 3.3V supply max. 500 mA
GND
ADC - ADS1115 (I2C)
IM1=1
NHD-2.4-240320CF-BSXV-F 320x240 TFT (4-wire SPI)
LiPo charger Supply: 3.7-6V R_PROG = 2K Charge rate 500mA (=max)
Accelerometer - ADXL345 (I2C)
Connectors
LED-A
I1: REM3 I2: REM2 I3: REM1 I11: LEAK I14: GPS_PPS I15: GPS_EXTINT
RS232 interface
Backup 3V supply max. 50 mA
IM0=0
Power supplies (main, backup and peripheral)
jumpers for when using regular UART (without MAX3232)
Remote control
Peripheral 5V supply max. 350 mA
VDD
SERCOM0: UART1 SERCOM1: I2C_EXT SERCOM2: UART3 SERCOM3: SPI (TFT) SERCOM4: I2C_INT SERCOM5: UART2 QSPI: QSPI (FLASH)
I2C
LiPo Charger
LED-K1-4

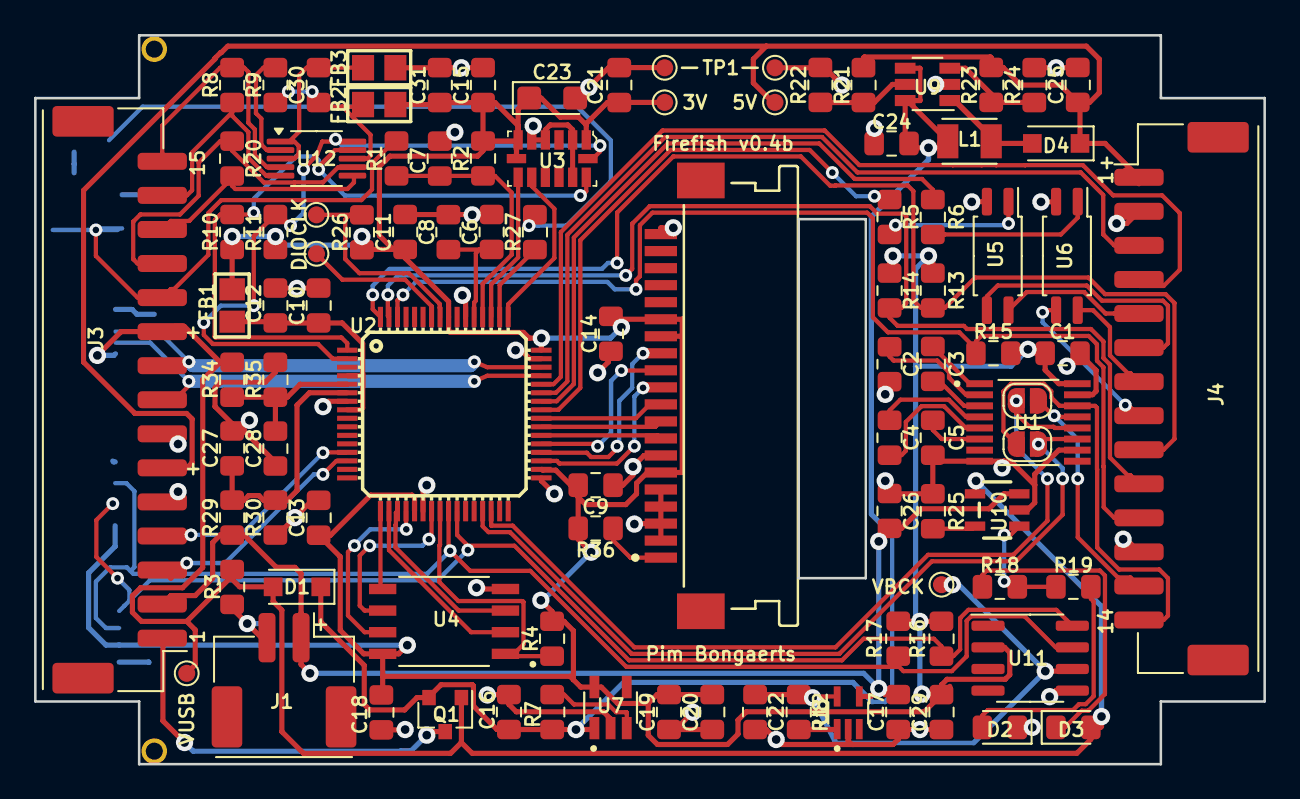
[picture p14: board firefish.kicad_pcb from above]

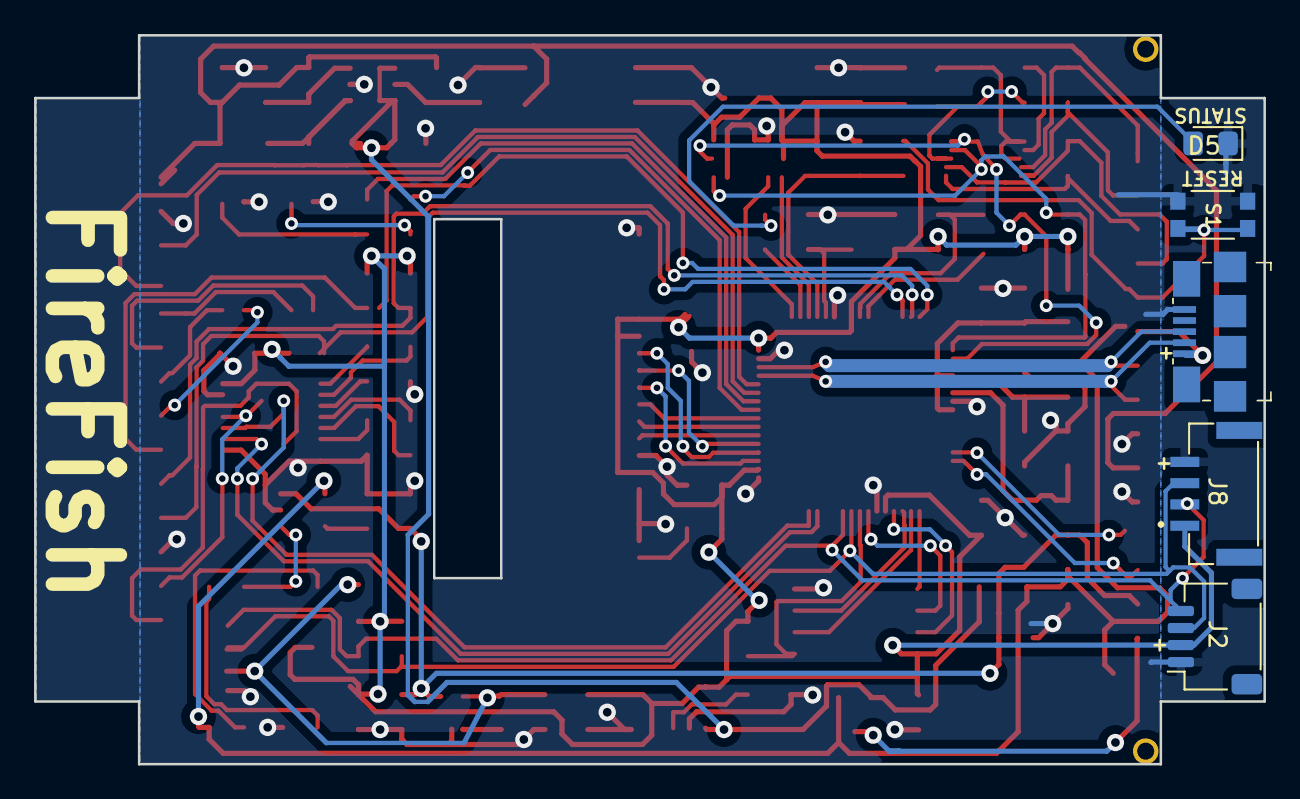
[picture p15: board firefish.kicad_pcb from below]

Board: 2 copper layers, 72.2 x 42.8 mm, 105 parts (5 on the bottom side), 80 nets.

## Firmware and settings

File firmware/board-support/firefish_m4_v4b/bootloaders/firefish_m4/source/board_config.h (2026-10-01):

#ifndef BOARD_CONFIG_H
#define BOARD_CONFIG_H

#define CRYSTALLESS    1

#define VENDOR_NAME "Pim Bongaerts"
#define PRODUCT_NAME "FireFish"
#define VOLUME_LABEL "FIREBOOT"
#define INDEX_URL "https://github.com/pimbongaerts/firefish"
#define BOARD_ID "FIREFISH_02"

#define USB_VID 0x239A
#define USB_PID 0x007D

#define LED_PIN PIN_PB23

#define BOOT_USART_MODULE                 SERCOM5
#define BOOT_USART_MASK                   APBAMASK
#define BOOT_USART_BUS_CLOCK_INDEX        MCLK_APBDMASK_SERCOM5
#define BOOT_USART_PAD_SETTINGS           UART_RX_PAD1_TX_PAD0
#define BOOT_USART_PAD3                   PINMUX_UNUSED
#define BOOT_USART_PAD2                   PINMUX_UNUSED
#define BOOT_USART_PAD1                   PINMUX_PA22D_SERCOM5_PAD1
#define BOOT_USART_PAD0                   PINMUX_PA23D_SERCOM5_PAD0
#define BOOT_GCLK_ID_CORE                 SERCOM5_GCLK_ID_CORE
#define BOOT_GCLK_ID_SLOW                 SERCOM5_GCLK_ID_SLOW

#endif

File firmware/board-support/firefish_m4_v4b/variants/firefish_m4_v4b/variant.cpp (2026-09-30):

/*
  Copyright (c) 2014-2015 Arduino LLC.  All right reserved.

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
  You should have received a copy of the GNU Lesser General Public
  License along with this library; if not, write to the Free Software
  Foundation, Inc., 51 Franklin St, Fifth Floor, Boston, MA  02110-1301  USA
*/

#include "variant.h"

/*
 * Pins descriptions
 */

//TCC0 IOSET 6
//TCC1 IOSET 1
//TC0 IOSET 1
//TC1 IOSET 1
//TC2 IOSET 2
//TC3 IOSET 1
//TC4 IOSET 1
const PinDescription g_APinDescription[]=
{
  // 0..30 - Digital pins
  // ----------------------
  // 0..5 - SERCOM/UART
  { PORTA, 04, PIO_SERCOM_ALT, PIN_ATTR_NONE, No_ADC_Channel, NOT_ON_PWM, NOT_ON_TIMER, EXTERNAL_INT_NONE}, /// UART1-TX: SERCOM0/PAD[0]
  { PORTA, 05, PIO_SERCOM_ALT, PIN_ATTR_NONE, No_ADC_Channel, NOT_ON_PWM, NOT_ON_TIMER, EXTERNAL_INT_NONE }, /// UART1-RX: SERCOM0/PAD[1]
  { PORTA, 23, PIO_SERCOM_ALT, PIN_ATTR_NONE, No_ADC_Channel, NOT_ON_PWM, NOT_ON_TIMER, EXTERNAL_INT_NONE}, /// UART2-TX: SERCOM5/PAD[0]
  { PORTA, 22, PIO_SERCOM_ALT, PIN_ATTR_NONE, No_ADC_Channel, NOT_ON_PWM, NOT_ON_TIMER, EXTERNAL_INT_NONE }, /// UART2-RX: SERCOM5/PAD[1]
  { PORTA, 12, PIO_SERCOM, PIN_ATTR_NONE, No_ADC_Channel, NOT_ON_PWM, NOT_ON_TIMER, EXTERNAL_INT_NONE}, /// UART3-TX: SERCOM2/PAD[0]
  { PORTA, 13, PIO_SERCOM, PIN_ATTR_NONE, No_ADC_Channel, NOT_ON_PWM, NOT_ON_TIMER, EXTERNAL_INT_NONE }, /// UART3-RX: SERCOM2/PAD[1]

  // 6..9 - SERCOM/I2C
  { PORTB, 12, PIO_SERCOM, PIN_ATTR_NONE, No_ADC_Channel, NOT_ON_PWM, NOT_ON_TIMER, EXTERNAL_INT_NONE}, /// SDA: SERCOM4/PAD[0]
  { PORTB, 13, PIO_SERCOM, PIN_ATTR_NONE, No_ADC_Channel, NOT_ON_PWM, NOT_ON_TIMER, EXTERNAL_INT_NONE }, /// SCL: SERCOM4/PAD[1]
  { PORTA, 0, PIO_SERCOM_ALT, PIN_ATTR_NONE, No_ADC_Channel, NOT_ON_PWM, NOT_ON_TIMER, EXTERNAL_INT_NONE}, /// SDA: SERCOM1/PAD[0]
  { PORTA, 1, PIO_SERCOM_ALT, PIN_ATTR_NONE, No_ADC_Channel, NOT_ON_PWM, NOT_ON_TIMER, EXTERNAL_INT_NONE }, /// SCL: SERCOM1/PAD[1]

  // 10..12 - SPI pins (MISO,MOSI,SCK)
  { PORTA, 18, PIO_SERCOM_ALT, PIN_ATTR_DIGITAL, No_ADC_Channel, NOT_ON_PWM, NOT_ON_TIMER, EXTERNAL_INT_NONE }, /// MISO: SERCOM3/PAD[2] = RX
  { PORTA, 17, PIO_SERCOM_ALT, PIN_ATTR_DIGITAL, No_ADC_Channel, NOT_ON_PWM, NOT_ON_TIMER, EXTERNAL_INT_NONE }, /// MOSI: SERCOM3/PAD[0] = TX
  { PORTA, 16, PIO_SERCOM_ALT, PIN_ATTR_DIGITAL, No_ADC_Channel, NOT_ON_PWM, NOT_ON_TIMER, EXTERNAL_INT_NONE }, /// SCK: SERCOM3/PAD[1] = TX

  // 13..18 QSPI (SCK, CS, IO0, IO1, IO2, IO3)
  { PORTB, 10, PIO_COM, PIN_ATTR_NONE, No_ADC_Channel, NOT_ON_PWM, NOT_ON_TIMER, EXTERNAL_INT_NONE }, /// QSPI_SCK
  { PORTB, 11, PIO_COM, PIN_ATTR_NONE, No_ADC_Channel, NOT_ON_PWM, NOT_ON_TIMER, EXTERNAL_INT_NONE }, /// QSPI_CS
  { PORTA, 8, PIO_COM, PIN_ATTR_NONE, No_ADC_Channel, NOT_ON_PWM, NOT_ON_TIMER, EXTERNAL_INT_NONE },  /// QSPI_DATA0
  { PORTA, 9, PIO_COM, PIN_ATTR_NONE, No_ADC_Channel, NOT_ON_PWM, NOT_ON_TIMER, EXTERNAL_INT_NONE },  /// QSPI_DATA1
  { PORTA, 10, PIO_COM, PIN_ATTR_NONE, No_ADC_Channel, NOT_ON_PWM, NOT_ON_TIMER, EXTERNAL_INT_NONE }, /// QSPI_DATA2
  { PORTA, 11, PIO_COM, PIN_ATTR_NONE, No_ADC_Channel, NOT_ON_PWM, NOT_ON_TIMER, EXTERNAL_INT_NONE }, /// QSPI_DATA3

  // 19..26 Digital Low
  { PORTA, 19, PIO_DIGITAL, PIN_ATTR_DIGITAL, No_ADC_Channel, NOT_ON_PWM, NOT_ON_TIMER, EXTERNAL_INT_NONE }, /// TFTRES
  { PORTB, 16, PIO_DIGITAL, PIN_ATTR_DIGITAL, No_ADC_Channel, NOT_ON_PWM, NOT_ON_TIMER, EXTERNAL_INT_NONE }, /// TFTCS
  { PORTB, 17, PIO_DIGITAL, PIN_ATTR_DIGITAL, No_ADC_Channel, NOT_ON_PWM, NOT_ON_TIMER, EXTERNAL_INT_NONE }, /// TFTDC
  { PORTA, 20, PIO_DIGITAL, PIN_ATTR_DIGITAL, No_ADC_Channel, NOT_ON_PWM, NOT_ON_TIMER, EXTERNAL_INT_NONE }, /// CAM1
  { PORTA, 21, PIO_DIGITAL, PIN_ATTR_DIGITAL, No_ADC_Channel, NOT_ON_PWM, NOT_ON_TIMER, EXTERNAL_INT_NONE }, /// CAM2
  { PORTB, 14, PIO_DIGITAL, PIN_ATTR_DIGITAL, No_ADC_Channel, NOT_ON_PWM, NOT_ON_TIMER, EXTERNAL_INT_14 }, /// GPS_PPS
  { PORTB, 15, PIO_DIGITAL, PIN_ATTR_DIGITAL, No_ADC_Channel, NOT_ON_PWM, NOT_ON_TIMER, EXTERNAL_INT_15 }, /// GPS_EXTINT
  { PORTA, 27, PIO_DIGITAL, PIN_ATTR_DIGITAL, No_ADC_Channel, NOT_ON_PWM, NOT_ON_TIMER, EXTERNAL_INT_11 }, /// LEAK

  // 27..29 Digital High
  { PORTB, 1, PIO_DIGITAL, PIN_ATTR_DIGITAL, No_ADC_Channel, NOT_ON_PWM, NOT_ON_TIMER, EXTERNAL_INT_3 }, /// REM_BUT3
  { PORTB, 2, PIO_DIGITAL, PIN_ATTR_DIGITAL, No_ADC_Channel, NOT_ON_PWM, NOT_ON_TIMER, EXTERNAL_INT_2 }, /// REM_BUT2
  { PORTB, 3, PIO_DIGITAL, PIN_ATTR_DIGITAL, No_ADC_Channel, NOT_ON_PWM, NOT_ON_TIMER, EXTERNAL_INT_1 }, /// REM_BUT1

  // 30 LED
  { PORTB, 23, PIO_DIGITAL, PIN_ATTR_PWM_G, No_ADC_Channel,  NOT_ON_PWM, NOT_ON_TIMER, EXTERNAL_INT_NONE  }, /// STATUS LED

  // 31..33 - Analog pins
  // ----------------------
  // 31..33 Analog
  { PORTB, 4, PIO_ANALOG, PIN_ATTR_ANALOG_ALT, ADC_Channel6, NOT_ON_PWM, NOT_ON_TIMER, EXTERNAL_INT_4 }, /// USBMON
  { PORTB, 5, PIO_ANALOG, PIN_ATTR_ANALOG_ALT, ADC_Channel7, NOT_ON_PWM, NOT_ON_TIMER, EXTERNAL_INT_5 }, /// BATMON
  { PORTB, 6, PIO_ANALOG, PIN_ATTR_ANALOG_ALT, ADC_Channel8, NOT_ON_PWM, NOT_ON_TIMER, EXTERNAL_INT_6 }, /// LIGHT
 
  // 34..36 - USB
  // --------------------
  { NOT_A_PORT, 0, PIO_NOT_A_PIN, PIN_ATTR_NONE, No_ADC_Channel, NOT_ON_PWM, NOT_ON_TIMER, EXTERNAL_INT_NONE }, /// USB Host enable DOES NOT EXIST ON THIS BOARD
  { PORTA, 24, PIO_COM, PIN_ATTR_NONE, No_ADC_Channel, NOT_ON_PWM, NOT_ON_TIMER, EXTERNAL_INT_NONE }, /// USB/DM
  { PORTA, 25, PIO_COM, PIN_ATTR_NONE, No_ADC_Channel, NOT_ON_PWM, NOT_ON_TIMER, EXTERNAL_INT_NONE }, /// USB/DP

} ;

const void* g_apTCInstances[TCC_INST_NUM+TC_INST_NUM]={ TCC0, TCC1, TCC2, TCC3, TCC4, TC0, TC1, TC2, TC3, TC4, TC5 } ;
const uint32_t GCLK_CLKCTRL_IDs[TCC_INST_NUM+TC_INST_NUM] = { TCC0_GCLK_ID, TCC1_GCLK_ID, TCC2_GCLK_ID, TCC3_GCLK_ID, TCC4_GCLK_ID, TC0_GCLK_ID, TC1_GCLK_ID, TC2_GCLK_ID, TC3_GCLK_ID, TC4_GCLK_ID, TC5_GCLK_ID } ;

// Multi-serial objects instantiation
SERCOM sercom0( SERCOM0 ) ;
SERCOM sercom1( SERCOM1 ) ;
SERCOM sercom2( SERCOM2 ) ;
SERCOM sercom3( SERCOM3 ) ;
SERCOM sercom4( SERCOM4 ) ;
SERCOM sercom5( SERCOM5 ) ;

Uart Serial1( &sercom0, PIN_SERIAL1_RX, PIN_SERIAL1_TX, PAD_SERIAL1_RX, PAD_SERIAL1_TX ) ;

void SERCOM0_0_Handler()
{
  Serial1.IrqHandler();
}
void SERCOM0_1_Handler()
{
  Serial1.IrqHandler();
}
void SERCOM0_2_Handler()
{
  Serial1.IrqHandler();
}
void SERCOM0_3_Handler()
{
  Serial1.IrqHandler();
}

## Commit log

2026-09-30 FireFish open-hardware release: KiCad design, firmware, enclosure, docs
    [PCBWay_positions.csv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]
2026-10-01 Updated schematic
    [firefish.kicad_pcb, firefish.kicad_sch, firefish_BOM.csv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]
2026-10-01 Cleaning up
    [firefish_carrier_long_simple.stl, firefish_carrier_short.stl, firefish_carrier_short_simple.stl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]

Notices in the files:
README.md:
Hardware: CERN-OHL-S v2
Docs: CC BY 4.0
